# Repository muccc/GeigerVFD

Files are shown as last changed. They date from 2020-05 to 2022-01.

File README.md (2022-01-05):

# Geiger counter with Vacuum fluorescent display
This repo is a collection of all the parts to build an [ESP32](https://www.espressif.com/en/products/socs/esp32) based handheld device to measure radioactivity with a [Geiger–Müller tube](https://en.wikipedia.org/wiki/Geiger%E2%80%93M%C3%BCller_tube) & display info on an [VFD](https://en.wikipedia.org/wiki/Vacuum_fluorescent_display).

Future plans are [Home Automation](https://esphome.io/) integration, logging radioactivity measurements over WiFi & displaying additional information like e.g. a Clock.

The device is be powered via Micro-USB port of the ESP32. Note that the current draw of the VFD may exceed the 500mA USB standard.

# PCB
The PCB is designed in [KiCad](https://www.kicad.org/). All source files are in the  [pcb](pcb) Subdirectory.

### Schematic:
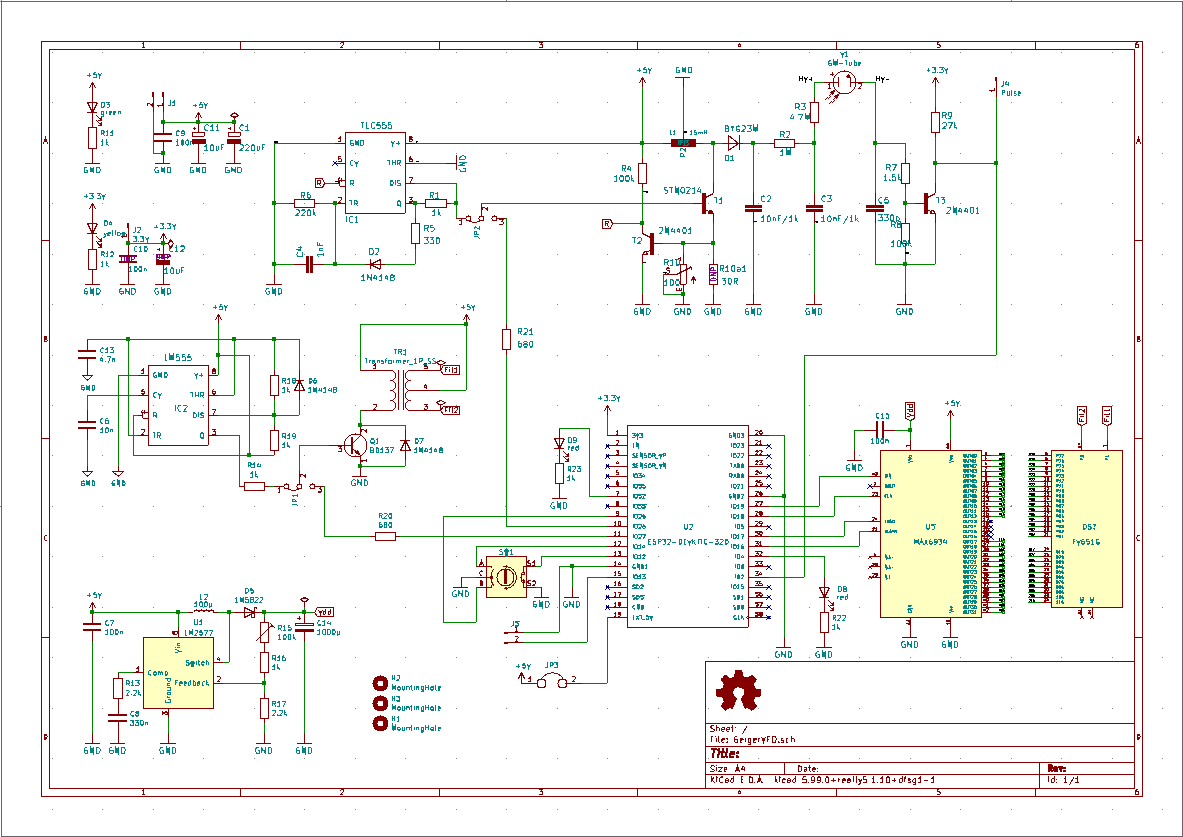
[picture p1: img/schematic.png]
schematic


### PCB:
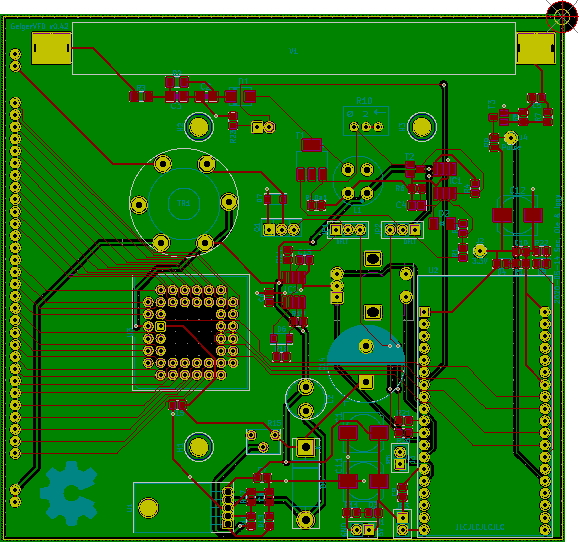
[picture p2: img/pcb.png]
pcb


### 3d render view:
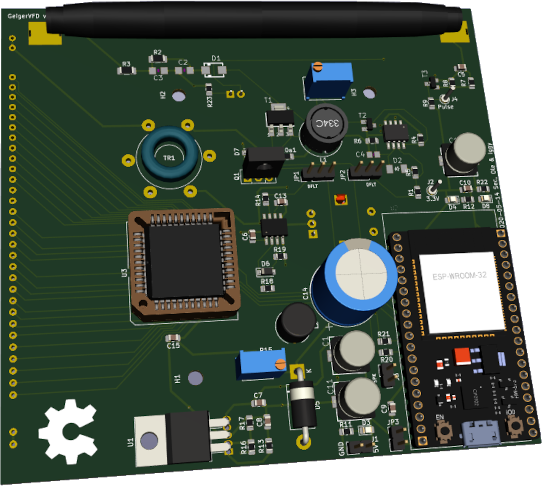
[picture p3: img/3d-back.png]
3d render back
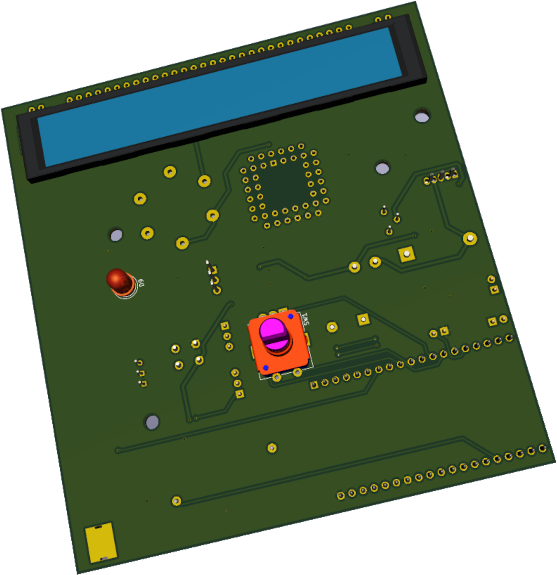
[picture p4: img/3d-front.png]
3d render front
 

# Case
The Case is designed in [OpenSCAD](https://openscad.org/). Sources reside in the [case](case/) Subdirectory.

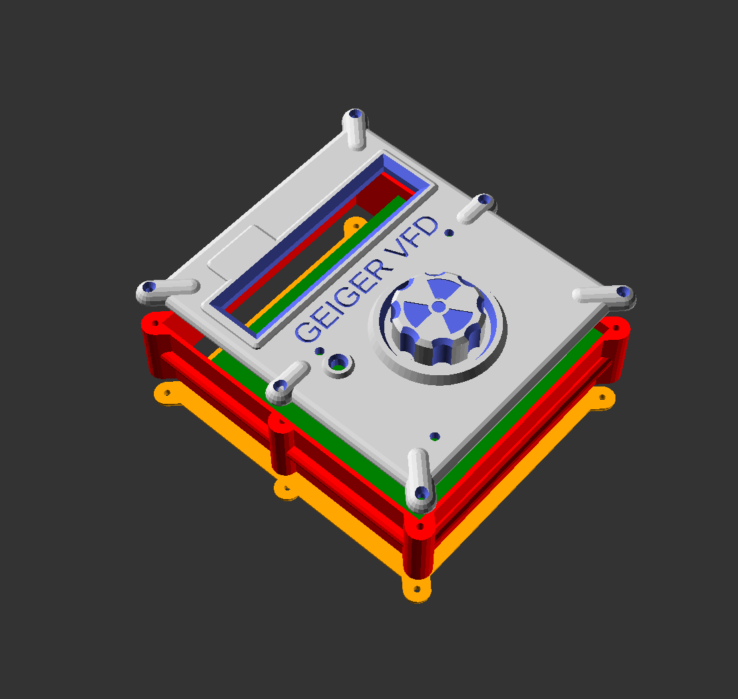
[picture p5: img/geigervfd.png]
plot


# Firmware
:warning: Work in Progress :warning:

The firmware is written using [Espressif-IDF](https://docs.espressif.com/projects/esp-idf/en/latest/esp32/get-started/) and lives in the [firmware](firmware/) directory.

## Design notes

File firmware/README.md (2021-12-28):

# Firmware for GeigerVFD

Standalone firmware for the GeigerVFD board

## Requirements

* Espressif IDF (https://docs.espressif.com/projects/esp-idf/en/latest/esp32/get-started/)

## Building

source ..../esp-idf/export.sh
idf.py build
idf.py flash

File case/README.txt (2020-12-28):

Geiger VFD case created by iggy@muc.ccc.de in OpenSCAD

inspired by https://twitter.com/80level/status/1240705664961449986

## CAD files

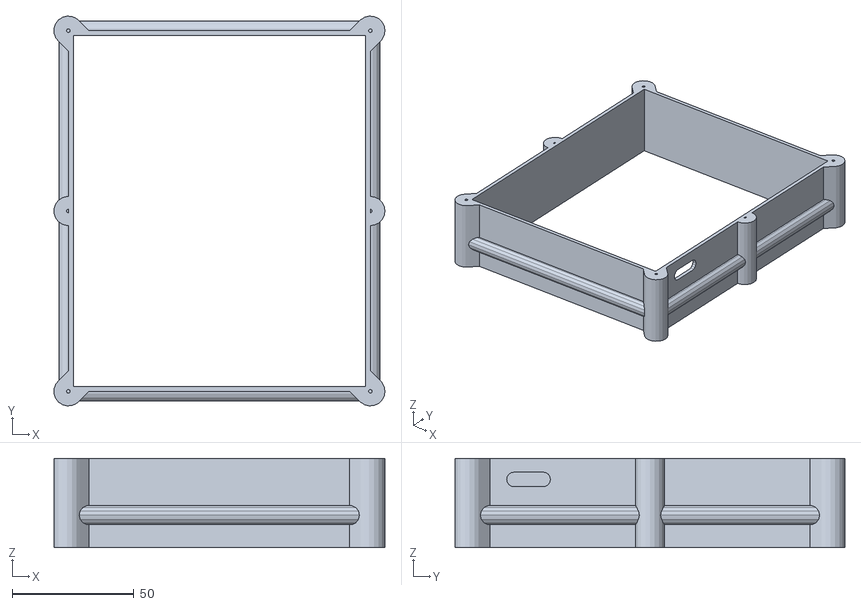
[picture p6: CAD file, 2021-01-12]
case/geigervfd_body.stl
136.1 x 160.3 x 36.6

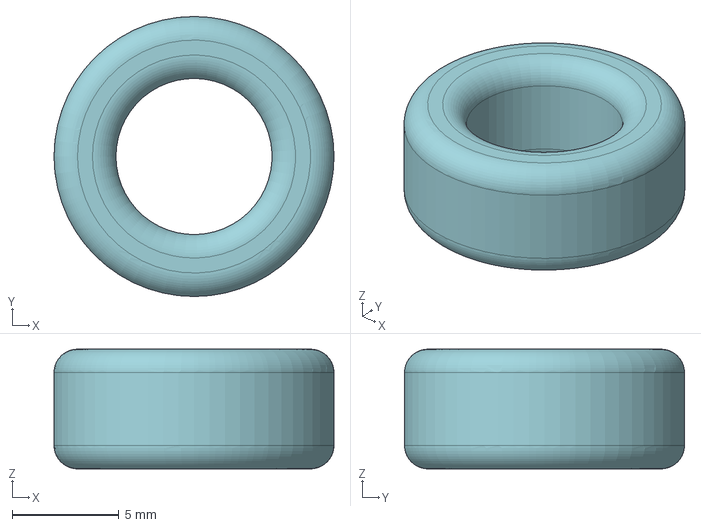
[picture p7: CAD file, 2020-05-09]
pcb/3d/Ferrite Core - EPCOS B64290L0044X038.step
13.1 x 13.1 x 5.60 mm

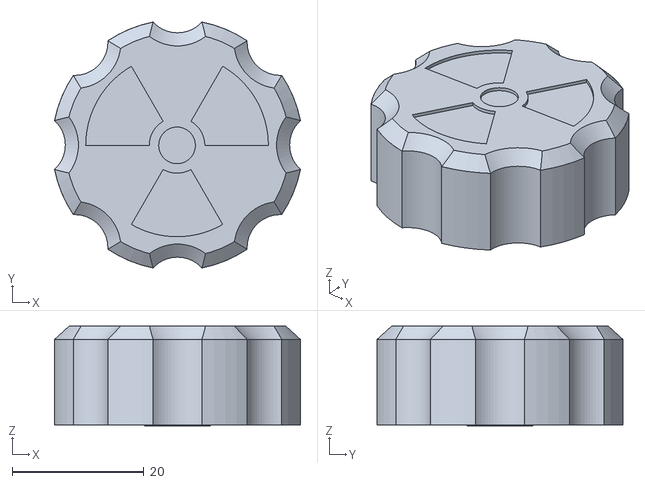
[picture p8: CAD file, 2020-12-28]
case/geigervfd_knob.stl
37.3 x 37.3 x 15.1

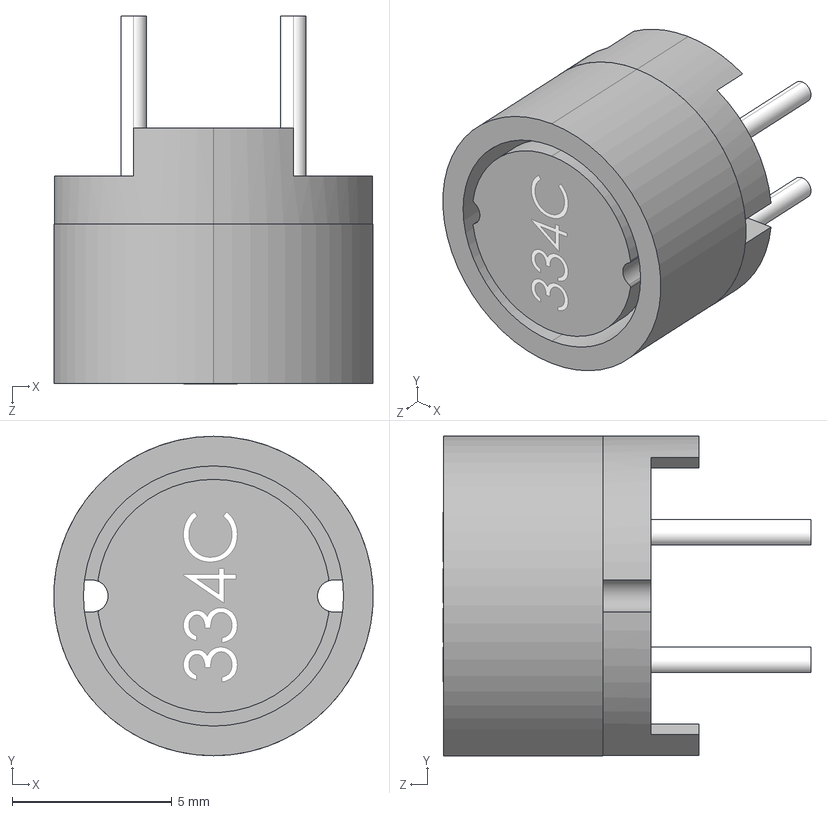
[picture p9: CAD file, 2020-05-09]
pcb/3d/mps_mag_1200lrs_thd_a.STEP
9.98 x 10.00 x 11.5 mm

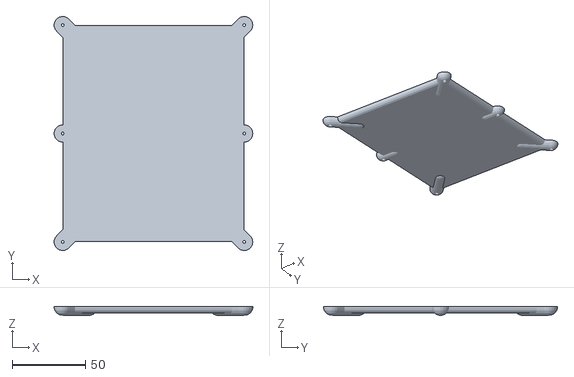
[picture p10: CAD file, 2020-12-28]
case/geigervfd_cover_bottom.stl
136.0 x 160.2 x 5.93

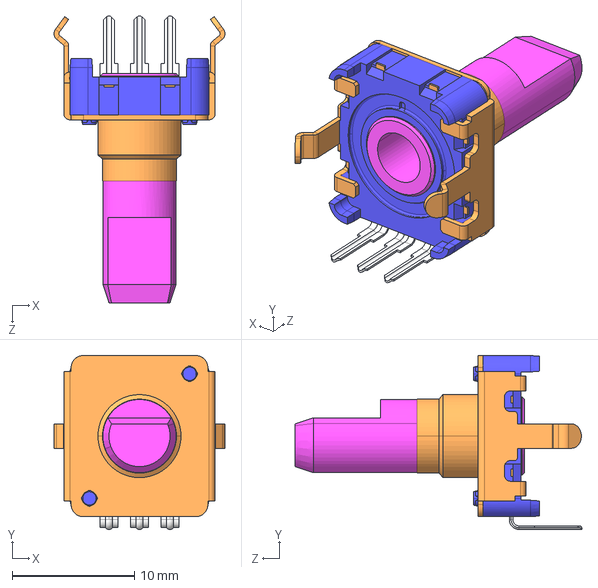
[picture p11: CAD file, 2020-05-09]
pcb/3d/EC12E-200.STEP
14.0 x 14.2 x 23.5 mm

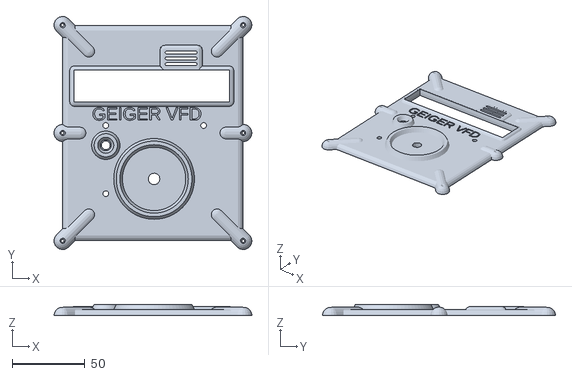
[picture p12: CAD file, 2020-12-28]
case/geigervfd_cover_top.stl
136.0 x 160.2 x 7.90

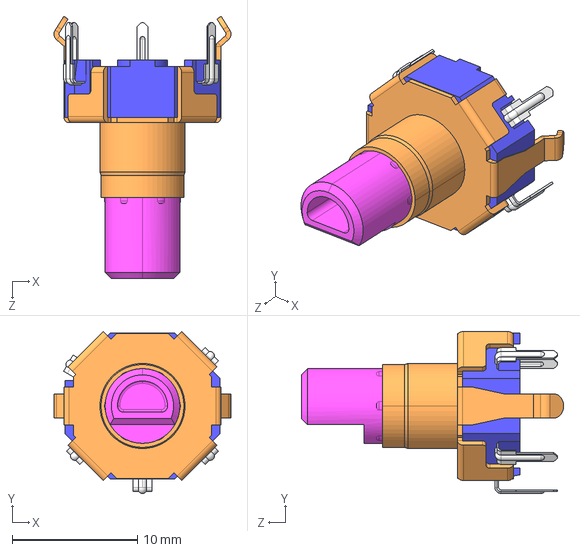
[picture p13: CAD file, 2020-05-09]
pcb/3d/EC12D1524403.step
14.1 x 13.0 x 21.0 mm

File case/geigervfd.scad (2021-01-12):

use<knob.scad>;

eps=0.01;

pcb_x = 109.7;
pcb_y = 117.35;
pcb_z = 1.6;

pcb_pad_top = 3;
pcb_pad_bottom = 27+5;
pcb_fit=1;

pcb_mount_holes = [ [23.2,29.46],
                    [23.2,76.32], 
                    [90.42,76.32] ];

pcb_led_pos = [23.2,62.74];//78.99];

pcb_mount_through = true;

pcb_mount_hole_d = 4;

case_wall_side = 2;

case_body_z = pcb_z+pcb_pad_top+pcb_pad_bottom;
//case_cover_h=5;

case_xl_oversize=3.5;
case_xr_oversize=5;

case_r=4.5;
case_y_oversize = 25;
case_cutout_dim=[pcb_x+2*pcb_fit+case_xl_oversize+case_xr_oversize,pcb_y+2*pcb_fit+case_y_oversize,case_body_z+2*eps];
case_body_dim=[case_cutout_dim[0]+2*case_wall_side,case_cutout_dim[1
]+2*case_wall_side,case_body_z];

case_offset = case_wall_side+pcb_fit;

case_top_dim=[case_body_dim[0],case_body_dim[1],case_r];
case_mount_d = 12;
case_mount_bore=1.5;
cover_mount_bore=2;

case_mounts=[[0,0,+1.5,+1.5],
            [0,case_body_dim[1],1.5,-1.5],
            [case_body_dim[0],0,-1.5,1.5],
            [case_body_dim[0],case_body_dim[1],-1.5,-1.5],
            [case_body_dim[0],case_body_dim[1]/2,-1,0],
            [0,case_body_dim[1]/2,1,0]
            ];

explode = 0;

usb_dim=[12,6];
usb_pos = [1,28.42/2+2.03+5];

has_buzzer=true;

display_size=[107,22,23];
display_pos=[1.3,92.38,-eps];

encoder_pos=[56.39,39.62,-eps];
encoder_bore=8;

module pcb(){
    translate([case_xl_oversize,0,0]) difference(){
        cube([pcb_x,pcb_y,pcb_z]);
        translate([0,0,-eps]) for (hole_pos=pcb_mount_holes)
            translate(hole_pos) cylinder(d=pcb_mount_hole_d, h=pcb_z+2*eps);
    }
}

module ring(d_ring, h_ring){
    difference(){
        cylinder(d1=d_ring+h_ring*3,d2=d_ring+h_ring*2,h=h_ring,$fn=64);
        cylinder(d1=d_ring,d2=d_ring+h_ring,h=h_ring+eps,$fn=64);
    }
}

module cube_rounded(dim,r,center=false){
    co = center?[0,0,-dim[2]/2]:[dim[0]/2,dim[1]/2];
    
    translate(co) hull() for(mx=[0,1], my=[0,1]) 
        mirror([mx,0,0])mirror([0,my,0])
        translate([(dim[0]/2)-r,(dim[1]/2)-r])
        cylinder(r=r, h=dim[2]);
}

module cube_cover(dim,center=false,invert=false) {
    co = center?[0,0,-dim[2]/2]:[dim[0]/2,dim[1]/2];
    r=dim[2];
    zz = invert?-dim[2]:0;
    translate(co) hull() for(mx=[0,1], my=[0,1]) 
        mirror([mx,0,0])mirror([0,my,0])
        translate([(dim[0]/2)-r,(dim[1]/2)-r])
        intersection(){
            sphere(r=r);
            translate([0,0,zz]) cylinder(r=dim[2],h=dim[2]);
        }
}

module body(){
    translate([0,0,-pcb_pad_bottom]) difference(){
        translate([-case_offset,-case_offset]){
        //union(){
            
            cube_rounded(case_body_dim,r=case_r);
            
            hull() for(ix=[0,1],iy=[0,1])translate([ix*case_body_dim[0],iy*case_body_dim[1],case_body_z/2-5]) sphere(r=case_r-0.5);
            
            for(mount = case_mounts)
                translate([mount[0],mount[1]]) mount_body(case_mount_d,case_body_z,mount[2],mount[3]);
        }
        translate([-pcb_fit,-pcb_fit,-eps]) cube(case_cutout_dim);
        
        
        //usb
        translate([pcb_x,usb_pos[1],pcb_pad_bottom-usb_dim[1]/2-usb_pos[0]])rotate([00,90,0]) hull() for(i=[-1,1]) translate([0,i*usb_dim[0]/2,0]) cylinder(d=usb_dim[1],h=60,center=true,$fn=16);
    }
}

module mount_body(d,h,dx=0,dy=0){
    difference(){
        hull(){
            cylinder(d=d,h=h);
            translate([dx*d,dy*d,0]) cylinder(d=d,h=h);
        }
        translate([0,0,-eps]) cylinder(d=case_mount_bore,h=h+2*eps,$fn=16);
    }
}

module mount_top(d,dx=0,dy=0,invert=false) {
    m=invert?1:0;
    mirror([0,0,m]) difference(){
        hull(){
            intersection(){
                sphere(d=d);
                cylinder(d=d,h=d);
            }
            translate([dx*d,dy*d,0]) intersection(){
                 sphere(d=d);
                 cylinder(d=d,h=d);
            }
        }
        translate([0,0,-eps]) cylinder(d=cover_mount_bore,h=d+2*eps,$fn=16);
        translate([0,0,d/2-case_mount_bore]) cylinder(d1=case_mount_bore,d2=cover_mount_bore*2,h=case_mount_bore,$fn=16);
    }
}
module cover(is_bottom=false){
    oz= is_bottom?-pcb_pad_bottom:pcb_pad_top+pcb_z;
    translate([-case_offset,-case_offset,oz]){
        difference(){
            cube_cover(case_top_dim,invert=is_bottom);
            
            for(i=[4,5]) translate([case_mounts[i][0],case_mounts[i][1],-10])cylinder(d=cover_mount_bore,h=20);
            
        }
            for(mount = case_mounts)
                translate([mount[0],mount[1]]) mount_top(case_mount_d,mount[2],mount[3],invert=is_bottom);
    }
}

module cover_bottom(){
    cover(is_bottom=true);
}

module cover_top() {
    z_top = case_r+pcb_pad_top;
    difference(){
        union(){
            cover(is_bottom=false);
            
            over =7.2;
            
            //display
            translate([case_xl_oversize,0,0])translate([-over/2,-over/2,z_top-0.5]) translate(display_pos) cube_cover([display_size[0]+over,display_size[1]+over,4]);
            
            //buzzer
            if(has_buzzer) translate([case_xl_oversize,0,0]) translate([60,112,z_top]) cube_cover([30,20,3.5]);
            
            //encoder
            translate([case_xl_oversize,0,0]) translate([0,0,z_top]) translate(encoder_pos) ring(42,5);
            
            //led
            translate([case_xl_oversize,0,0]) translate([0,0,z_top]) translate(pcb_led_pos) ring(6,5);
        }
        translate([case_xl_oversize,0,0]) translate(display_pos) cube(display_size);
            
        over2 = 1;
        //display
        translate([case_xl_oversize,0,0]) translate(display_pos) hull(){
            translate([0,0,z_top]) cube([display_size[0],display_size[1],eps]);
            translate([-over2/2,-over2/2,z_top+3])cube([display_size[0]+over2,display_size[1]+over2,eps]);
        }
        translate([case_xl_oversize,0,0]) translate(encoder_pos) cylinder(d=encoder_bore,h=23);
        translate([case_xl_oversize,0,0]) translate([0,0,-eps]) for (mount=pcb_mount_holes) translate(mount) cylinder(d=pcb_mount_hole_d,h=case_r+2*eps+10,$fn=16);
            
        translate([pcb_x/2,80,z_top]) linear_extrude(2)color("black") text("GEIGER VFD",halign="center", font="StalinistOne",size=9);
        
        translate([case_xl_oversize,0,0]) translate(pcb_led_pos) cylinder(d=6,h=case_r+2*eps+10,$fn=16);
    
        if(has_buzzer) translate([case_xl_oversize,0,0]) translate([60,111.5,z_top])
            for(i=[0:2]) {
                translate([0,i*4+7,0]) 
                hull() for(j=[0,1]) translate([j*20+5,0,0]) cylinder(d=2,h=10,$fn=16,center=true);
        }
    }
    if(false) translate([0,0,pcb_z]) for (mount=pcb_mount_holes) translate(mount) difference(){
        cylinder(d=pcb_mount_hole_d*2,h=pcb_pad_top,$fn=16);
        #translate([0,0,-eps]) cylinder(d=pcb_mount_hole_d,h=pcb_pad_top,$fn=16);
    }
}

//color("green") pcb();
color("red") body();

translate([0,0,explode])  cover_top();
translate([0,0,-explode]) color("orange") cover_bottom();
translate([case_xl_oversize,0,0]) translate([encoder_pos[0],encoder_pos[1], pcb_pad_top+case_r+1*explode]) knob();

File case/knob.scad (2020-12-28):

eps = 0.01;
$fn=64;

knob_d = 38;
knob_h = 15;
knob_chamfer=2;

grab_n = 8;
grab_d = 10;
grab_offset=3;

back_d=knob_d-10;
back_h=knob_h-4;

axis_h=0.1;
axis_d=6;
axis_d_flat=5;
axis_flat_offset=4;
axis_d_i=3.2;



module engraving(){
    translate([-0.4,0.5]) linear_extrude(2) scale([0.055,0.055]) import("rad.svg");
    //for(dia=[13,26]) difference(){
    //    cylinder(d=dia,h=2);
    //    translate([0,0,eps]) cylinder(d=dia-1,h=2);
    //}
}

module cylinder_chamfered(d,h,c,c_out=false){
    cdir= c_out?-1:1;
    cylinder(d=d,h=h+eps-c);
    translate([0,0,h-c]) cylinder(d1=d,d2=d-(cdir*c*2),h=c);
}

module knob(){
    difference(){
        union(){
            //main
            cylinder_chamfered(h=knob_h, d=knob_d, c=knob_chamfer);
        }
        
        //grab cutouts
        for(az=[0:360/grab_n:360]) rotate([0,0,az]) translate([knob_d/2+grab_offset,0,-eps]) cylinder_chamfered(d=grab_d,h=knob_h+2*eps,c=knob_chamfer, c_out=true);
    
        //back cutout
        translate([0,0,-eps]) cylinder(d=back_d,h=back_h);
        
        translate([0,0,knob_h-0.5]) engraving();
    }
    
    //axis
    
    
    difference(){
        union(){
            for(az=[0,90]) rotate([0,0,az]) translate([0,0,back_h/2]) cube([back_d+eps,1,back_h],center=true);

            translate([0,0,-axis_h+eps]) cylinder(d=axis_d+4,h=axis_h-eps);
            cylinder(d2=axis_d*2+4,d1=axis_d+4,h=back_h);

        }
        
        difference(){
            translate([0,0,-axis_h]) cylinder(d=axis_d,h=axis_h+knob_h);
                
            translate([axis_d_flat,0,-(axis_h)/2+(knob_h/2)]) cube([axis_d,axis_d,axis_h+knob_h+eps],center=true);
            
        }
    }
}

rotate([180,0,0]) knob();

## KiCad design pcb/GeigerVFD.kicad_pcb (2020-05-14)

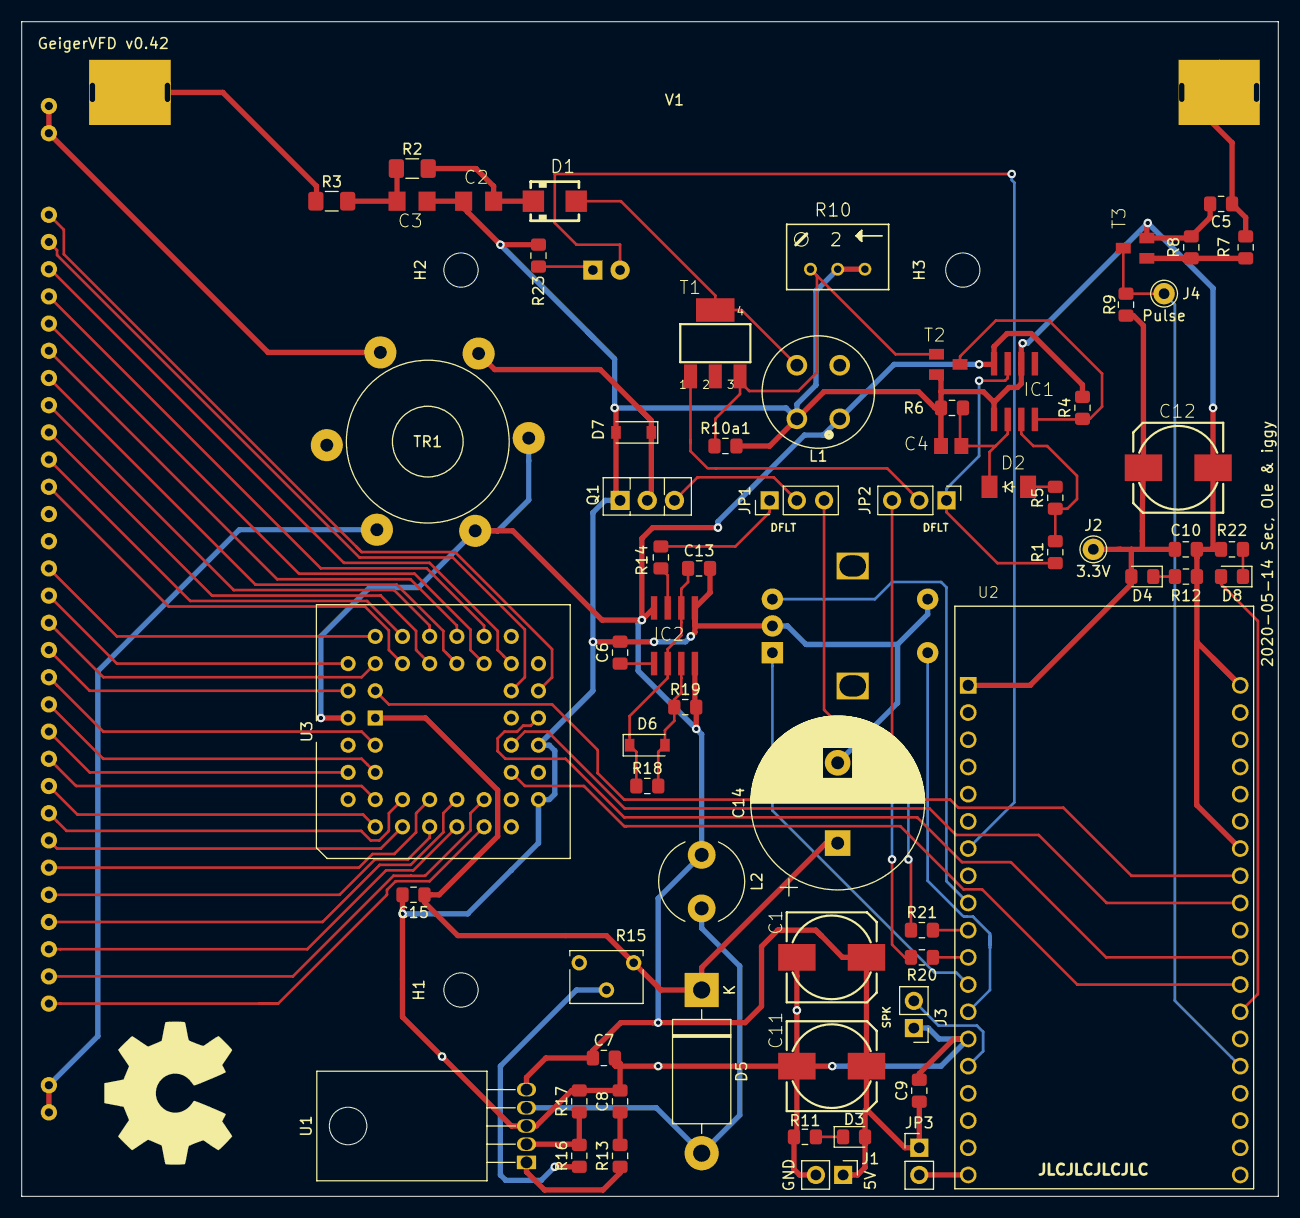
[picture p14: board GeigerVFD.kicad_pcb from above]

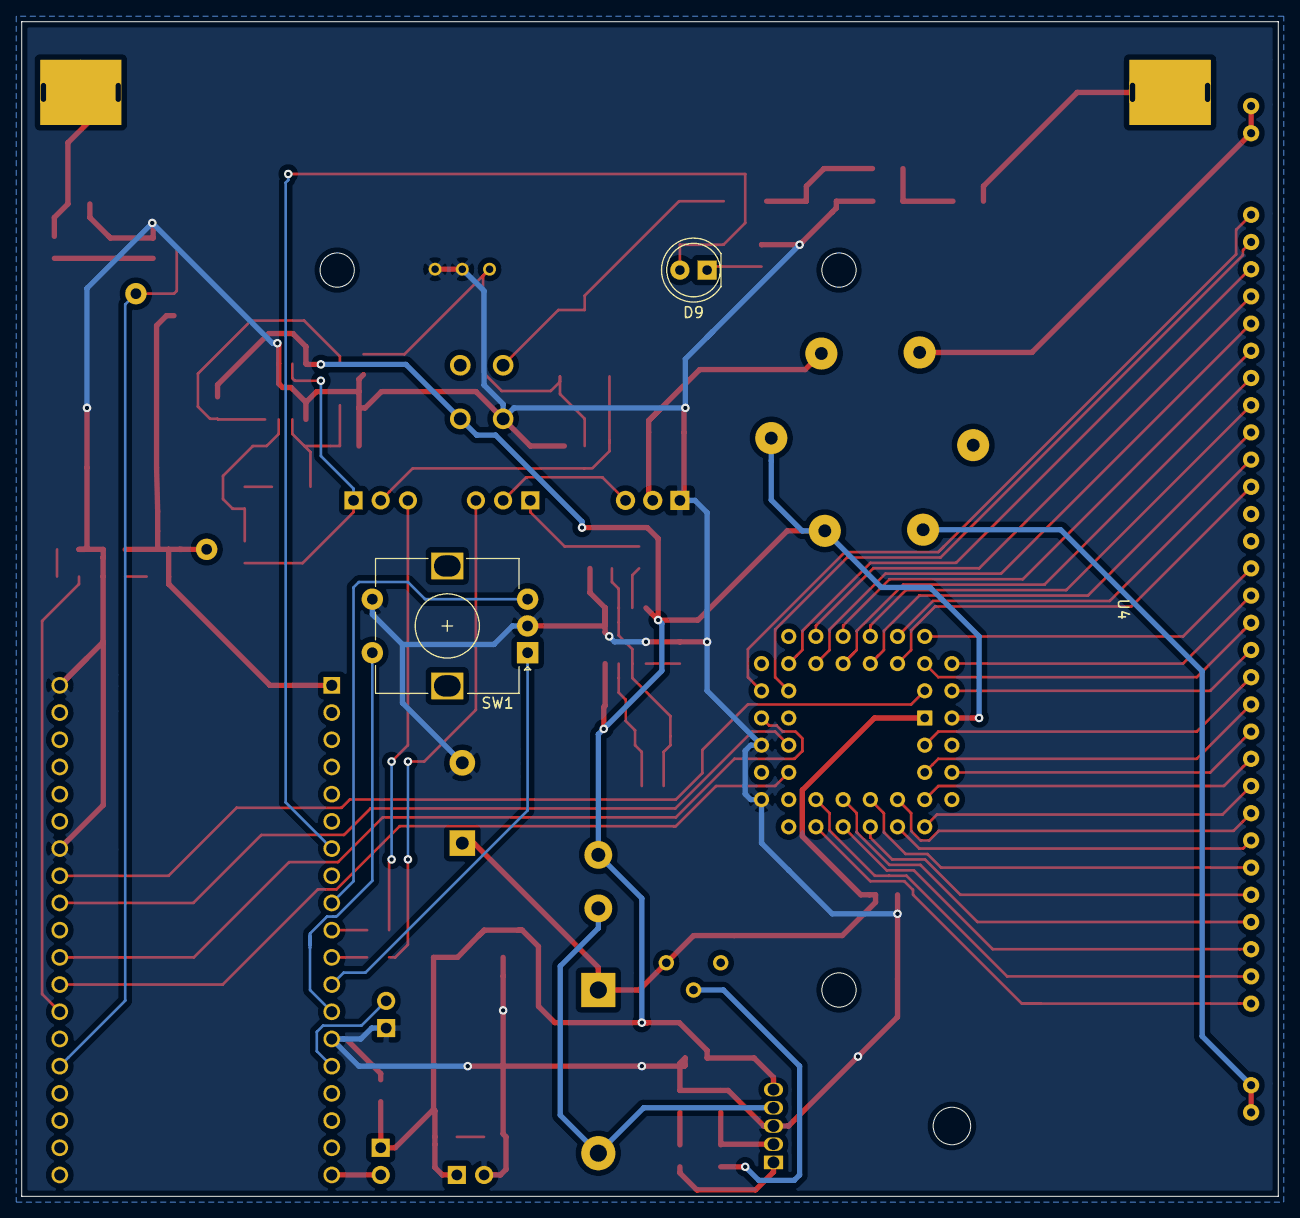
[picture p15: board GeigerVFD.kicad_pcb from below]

Board: 2 copper layers, 117.3 x 109.7 mm, 74 parts (3 on the bottom side), 79 nets.

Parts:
C1: 220uF; 153CLV-0810
C2, C3: 10nF/1k; C1206
C4: 1nF; C0805
C5: 330p; C_0805_2012Metric_Pad1.15x1.40mm_HandSolder
C6: 10n; C_0805_2012Metric_Pad1.15x1.40mm_HandSolder
C7, C9, C10, C15: 100n; C_0805_2012Metric_Pad1.15x1.40mm_HandSolder
C8: 330n; C_0805_2012Metric_Pad1.15x1.40mm_HandSolder
C11, C12: 10uF; 153CLV-0810
C13: 4.7n; C_0805_2012Metric_Pad1.15x1.40mm_HandSolder
C14: 1000µ; CP_Radial_D16.0mm_P7.50mm
D1: BYG23M; SMA
D2: 1N4148; SOD-123_MINI-SMA
D3: green; LED_0805_2012Metric_Pad1.15x1.40mm_HandSolder
D4: yellow; LED_0805_2012Metric_Pad1.15x1.40mm_HandSolder
D5: 1N5822; D_DO-201AD_P15.24mm_Horizontal
D6, D7: 1N4148; D_SOD-123
D8: red; LED_0805_2012Metric_Pad1.15x1.40mm_HandSolder
D9: red; LED_D5.0mm
H1, H2, H3: MountingHole; MountingHole_3.2mm_M3_DIN965
IC1: TLC555; SO08
IC2: LM555; SO08
J1, J3: Conn_01x02_Male; PinHeader_1x02_P2.54mm_Vertical
J2: 3.3V; Pin_D1.0mm_L10.0mm
J4: Pulse; Pin_D1.0mm_L10.0mm
JP1, JP2: Jumper3; PinHeader_1x03_P2.54mm_Vertical
JP3: Jumper; PinHeader_1x02_P2.54mm_Vertical
L1: 15mH; 1200LRS
L2: 100µ; L_Radial_D7.8mm_P5.00mm_Fastron_07HCP
LOGO1: Logo_Open_Hardware_Large; OSHW-Symbol_13.4x12mm_SilkScreen
Q1: BD137; TO-126-3_Vertical
R1, R11, R12, R14, R16, R18, R19, R22, R23: 1k; R_0805_2012Metric_Pad1.15x1.40mm_HandSolder
R2: 1M; R_1206_3216Metric_Pad1.42x1.75mm_HandSolder
R3: 4.7M; R_1206_3216Metric_Pad1.42x1.75mm_HandSolder
R4, R8: 100k; R_0805_2012Metric_Pad1.15x1.40mm_HandSolder
R5: 330; R_0805_2012Metric_Pad1.15x1.40mm_HandSolder
R6: 220k; R_0805_2012Metric_Pad1.15x1.40mm_HandSolder
R7: 1.5k; R_0805_2012Metric_Pad1.15x1.40mm_HandSolder
R9: 27k; R_0805_2012Metric_Pad1.15x1.40mm_HandSolder
R10: 100; RJ9W
R10a1: 30R; R_0805_2012Metric_Pad1.15x1.40mm_HandSolder
R13, R17: 2.2k; R_0805_2012Metric_Pad1.15x1.40mm_HandSolder
R15: 100k; Potentiometer_Vishay_T73XX_Horizontal
R20, R21: 680; R_0805_2012Metric_Pad1.15x1.40mm_HandSolder
SW1: Rotary_Encoder_Switch; RotaryEncoder_Alps_EC12E-Switch_Vertical_H20mm
T1: STN0214; SOT223
T2, T3: 2N4401; SOT23
TR1: Transformer_1P_SS; Transformer_Toroid_Tapped_Horizontal_D14.0mm_Amidon-T50
U1: LM2577; TO-220-5_Horizontal_TabDown
U2: ESP32-DEVKITC-32D; MODULE_ESP32-DEVKITC-32D
U3: MAX6934; PLCC-44_THT-Socket
U4: FV651G
V1: GM-Tube; Tube

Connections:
+3V3: C10.1, C12.+, D4.2, J2.1, R9.2, U2.1
+5V: C1.+, C7.1, C9.1, C11.+, D3.2, IC1.8, IC2.4, IC2.8, J1.1, JP3.1, L1.P1, L2.1, R4.2, R19.2, TR1.1, TR1.4, U1.5, U3.44
/01G: U3.38, U4.24
/02G: U3.37, U4.25
/03G: U3.36, U4.26
/04G: U3.35, U4.27
/05G: U3.34, U4.28
/06G: U3.33, U4.29
/07G: U3.32, U4.30
/08G: U3.31, U4.31
/09G: U3.30, U4.32
/10G: U3.27, U4.33
/11G: U3.26, U4.34
/HV+: R3.1, V1.1
/HV-: C5.1, R7.1, V1.2
/P01: U3.39, U4.21
/P02: U3.40, U4.20
/P03: U3.41, U4.19
/P04: U3.42, U4.18
/P05: U3.3, U4.17
/P06: U3.5, U4.16
/P07: U3.4, U4.15
/P08: U3.8, U4.14
/P09: U3.7, U4.13
/P10: U3.10, U4.12
/P11: U3.9, U4.11
/P12: U3.12, U4.10
/P13: U3.11, U4.9
/P14: U3.14, U4.8
/P15: U3.13, U4.7
/P16: U3.16, U4.6
/P17: U3.15, U4.5
Fil1: TR1.5, U4.1, U4.2
Fil2: TR1.3, U4.37, U4.38
GND: C1.-, C2.2, C3.2, C4.1, C5.2, C6.2, C7.2, C8.2, C9.2, C10.2, C11.-, C12.-, C13.2, C14.2, C15.2, D7.2, IC1.1, IC1.6, IC2.1, J1.2, J3.1, L1.P4, Q1.1, R6.2, R8.2, R10.E, R10.S, R10a1.2, R11.2, R12.2, R17.2, R22.2, R23.2, SW1.C, SW1.S2, T2.2, T3.2, U1.3, U2.14, U2.20, U2.26, U3.18, U3.22
unnamed: C2.1, D1.C, R2.2
unnamed: C3.1, R2.1, R3.2
unnamed: C4.2, D2.C, IC1.2, R6.1
unnamed: C6.1, IC2.5
unnamed: C8.1, R13.2
unnamed: C13.1, D6.1, IC2.2, IC2.6, R18.1
unnamed: D1.A, L1.P3, T1.4
unnamed: D2.A, R5.2
unnamed: D3.1, R11.1
unnamed: D4.1, R12.1
unnamed: D5.2, L2.2, U1.4
unnamed: D6.2, IC2.7, R18.2, R19.1
unnamed: D7.1, Q1.2, TR1.2
unnamed: D8.1, R22.1
unnamed: D8.2, U2.32
unnamed: D9.1, R23.1
unnamed: D9.2, U2.7
unnamed: IC1.3, R1.2, R5.1
unnamed: IC1.7, JP2.1, R1.1
unnamed: IC2.3, R14.2
unnamed: J3.2, U2.15
unnamed: J4.1, R9.1, T3.3, U2.34
unnamed: JP1.1, R14.1
unnamed: JP1.2, Q1.3
unnamed: JP1.3, R20.2
unnamed: JP2.2, T1.1
unnamed: JP2.3, R21.1
unnamed: JP3.2, U2.19
unnamed: R7.2, R8.1, T3.1
unnamed: R10.A, R10a1.1, T1.3, T2.1
unnamed: R13.1, U1.1
unnamed: R15.2, R16.1
unnamed: R16.2, R17.1, U1.2
unnamed: R20.1, U2.11
unnamed: R21.2, U2.10
unnamed: SW1.A, U2.12
unnamed: SW1.B, U2.9
unnamed: SW1.S1, U2.13
unnamed: U2.27, U3.43
unnamed: U2.28, U3.23
unnamed: U2.30, U3.24
unnamed: U2.31, U3.21
R: IC1.4, R4.1, T2.3
Vdd: C14.1, C15.1, D5.1, R15.1, U3.1

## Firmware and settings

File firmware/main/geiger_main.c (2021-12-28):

/* Hello World Example

   This example code is in the Public Domain (or CC0 licensed, at your option.)

   Unless required by applicable law or agreed to in writing, this
   software is distributed on an "AS IS" BASIS, WITHOUT WARRANTIES OR
   CONDITIONS OF ANY KIND, either express or implied.
*/
#include <stdio.h>
#include <stdlib.h>
#include <string.h>
#include <unistd.h>
#include "sdkconfig.h"
#include "freertos/FreeRTOS.h"
#include "freertos/task.h"
#include "freertos/queue.h"
#include "driver/gpio.h"
#include "driver/spi_master.h"
#include "driver/ledc.h"
#include "esp_system.h"
#include "esp_spi_flash.h"
#include "esp_timer.h"
#include "esp_log.h"

#include "rotary_encoder.h"

/* esp32 GPIO pin mappings */
#define PIN_LED    32
#define PIN_PWRLED  4

#define PIN_LOAD   17
#define PIN_BLANK  16
#define PIN_CLK    18
#define PIN_DIN    19

#define PIN_BRIGHT 27

#define PIN_ROT1   14
#define PIN_ROT2   25

/* OUT pins of MAX6934 */
#define OUT(x) (1<<(31-x))

/* VFD - G pins */
#define G01 OUT(27)  // symbols
#define G02 OUT(26)  // rightmost
#define G03 OUT(25)
#define G04 OUT(24)
#define G05 OUT(23)
#define G06 OUT(22)
#define G07 OUT(21)
#define G08 OUT(20)
#define G09 OUT(19)
#define G10 OUT(18)
#define G11 OUT(17)  // leftmost

unsigned int grids[]={G11,G10,G09,G08,G07,G06,G05,G04,G03,G02,G01};  // left to right

/* VFD - P pins */
#define P01 OUT(28)  /* s1 */
#define P02 OUT(29)  /* s2 */
#define P03 OUT(30)  /* a  */
#define P04 OUT(31)  /* b  */
#define P05 OUT( 0)  /* f  */
#define P06 OUT( 2)  /* k  */
#define P07 OUT( 1)  /* j  */
#define P08 OUT( 4)  /* h  */
#define P09 OUT( 3)  /* m  */
#define P10 OUT( 6)  /* g  */
#define P11 OUT( 5)  /* n  */
#define P12 OUT( 8)  /* p  */
#define P13 OUT( 7)  /* r  */
#define P14 OUT(10)  /* c  */
#define P15 OUT( 9)  /* e  */
#define P16 OUT(12)  /* d  */
#define P17 OUT(11)  /* s3 */

/* P locations according to VFD datasheet:
    ---    a           3
   |\|/| fhjkb   5  8  7  6  4
    - -   g m      10     9
   |/|\| erpnc  15 13 12 11 14
    ---    d          16
 */

const int ascii[] = {
	P03|P05|P04|P10|P09|P15|P14,  /* a */
//	P05|P08|P10|P15|P13,          /* b */
//	P05|P15|P03|P16|P06|P11|P10,  /* b v2 */
	P05|P15|P10|P09|P14|P16,      /* b small */
	P03|P05|P15|P16,              /* c */
//	P05|P08|P15|P13,              /* d */
	P15|P10|P09|P16|P04|P14,      /* d small */
	P03|P05|P10|P15|P16,          /* e */
	P03|P05|P10|P15,              /* f */
	P03|P05|P15|P16|P11,          /* g */
	P05|P15|P10|P09|P04|P14,      /* h */
	P07|P12,                      /* i */
//	P07|P12|P16|P15,              /* j */
	P04|P14|P16|P15,              /* j v2 */
//	P07|P06|P12|P11,              /* k */
	P05|P15|P10|P06|P11,          /* k new */
	P05|P15|P16,                  /* l */
	P05|P15|P03|P07|P04|P14,      /* m */
	P05|P15|P03|P04|P14,          /* n */
	P03|P05|P04|P15|P14|P16,      /* o */
	P03|P05|P04|P15|P10|P09,      /* p */
	P03|P05|P04|P15|P14|P16|P11,  /* q */
	P03|P05|P15|P04|P09|P10|P11,  /* r */
//	P03|P07|P04|P09|P11|P12,      /* r v2 */
	P03|P05|P10|P09|P14|P16,      /* s */
	P03|P07|P12,                  /* t */
	P05|P15|P16|P04|P14,          /* u */
	P05|P15|P13|P06,              /* v */
	P05|P15|P16|P04|P14|P12,      /* w */
	P08|P06|P13|P11,              /* x */
	P08|P06|P12,                  /* y */
//	P03|P06|P13|P16,              /* z */
	P03|P06|P13|P16|P10|P09,      /* z v2 */
};


const int digit[] = {
	P03|P05|P04|P14|P15|P16,         // 0
	P04|P14,                         // 1
	P03|P04|P10|P09|P15|P16,         // 2
	P03|P04|P10|P09|P14|P16,         // 3
	P05|P10|P09|P04|P14,             // 4
	P03|P05|P10|P09|P14|P16,         // 5
	P03|P05|P10|P09|P15|P14|P16,     // 6
	P03|P04|P14,                     // 7
	P03|P05|P04|P10|P09|P15|P14|P16, // 8
	P03|P05|P04|P10|P09|P14|P16,     // 9
};


/* special symbols
             s1 s2 s3
	11G  <  >
	10G  bd
	09G  B  C
	08G
	07G  [] [] :
	06G  [] []
	05G  [] []
	04G  [] []
	03G  [] []
	02G  <  <
	01G  CCC -> <- ( ) analog digital (p11 - p17)
 */

#define SYM_CCC        G01|P11
#define SYM_LEFTARROW  G01|P12
#define SYM_RIGHTARROW G01|P13
#define SYM_LEFTPAREN  G01|P14
#define SYM_RIGHTPAREN G01|P15
#define SYM_ANALOG     G01|P16
#define SYM_DIGITAL    G01|P17
#define SYM_COLON      G07|P17
#define SYM_LEFT       G11|P01
#define SYM_RIGHT      G11|P02
#define SYM_DOLBY      G10|P01
#define SYM_B          G09|P01
#define SYM_C          G09|P02
#define SYM_PIP0       G07|P02
#define SYM_PIP1       G07|P01
#define SYM_PIP2       G06|P02
#define SYM_PIP3       G06|P01
#define SYM_PIP4       G05|P02
#define SYM_PIP5       G05|P01
#define SYM_PIP6       G04|P02
#define SYM_PIP7       G04|P01
#define SYM_PIP8       G03|P02
#define SYM_PIP9       G03|P01
#define SYM_REV_L      G02|P01
#define SYM_REV_R      G02|P02

unsigned int const pips[]={ SYM_PIP0, SYM_PIP1, SYM_PIP2, SYM_PIP3, SYM_PIP4, SYM_PIP5, SYM_PIP6, SYM_PIP7, SYM_PIP8, SYM_PIP9};

/* display high level */
#define DISPLAY_LEN 11
#define DISPLAY_TEXT_LEN (DISPLAY_LEN-1)
unsigned int outbuf[DISPLAY_LEN] = {0,0,0,0,0,0,0,0,0,0,0};

void vfd_write(char *str, unsigned char flags){
	int out=0;
	int in=0;

	// clear display
	for (out=0;out<DISPLAY_LEN;out++)
		outbuf[out]=0;

	out=DISPLAY_TEXT_LEN-strlen(str); // right-justify by default
	assert(out>=0);
	if (out<0)
		out=0;

	while ( str[in]!=0 && (in+out)<DISPLAY_TEXT_LEN ){
		char c=str[in];
		if (c>='0' && c<='9')
			outbuf[in+out]=digit[c-'0'];
		else if (c>='a' && c<='z')
			outbuf[in+out]=ascii[c-'a'];
		else if (c=='_')
			outbuf[in+out]=P16;
		else if (c=='-')
			outbuf[in+out]=P10|P09;
		else if (c=='+')
			outbuf[in+out]=P10|P09|P07|P12;
		else if (c=='<')
			outbuf[in+out]=P06|P11;
		else if (c=='>')
			outbuf[in+out]=P08|P13;
		else if (c==' ')
			outbuf[in+out]=0;
		else
			outbuf[in+out]=P10; /* error indicator */
		in++;
	};
};

void vfd_symbol(int sym){
	int x;
	
	for(x=0;x<DISPLAY_LEN;x++){
		if (sym&grids[x])
			outbuf[x]|= sym & ~grids[x];
	};
};

/* display low level */
static void display_timer_callback(void* arg);

spi_device_handle_t spi; // global spi handle
spi_transaction_t spi_t;

void spi_post_transfer_callback(spi_transaction_t *t) {
	int dc=(int)t->user;
	if (dc==1){
		ets_delay_us(1);
		gpio_set_level(PIN_LOAD, 1);
		ets_delay_us(1);
		gpio_set_level(PIN_LOAD, 0);
	};
}

void setup_display_spi(){
	esp_err_t ret;
	spi_bus_config_t buscfg={
		.miso_io_num=-1,
		.mosi_io_num=PIN_DIN,
		.sclk_io_num=PIN_CLK,
		.quadwp_io_num=-1,
		.quadhd_io_num=-1,
		.max_transfer_sz=32,
	};
	spi_device_interface_config_t devcfg={
		.clock_speed_hz=1*1000*1000,         // Clock out at 1 MHz (max=5MHz?)
		.mode=0,                             // SPI mode 0
		.spics_io_num=-1,                    // no CS pin
		.queue_size=7,                       // We want to be able to queue 7 transactions at a time
		.post_cb=spi_post_transfer_callback, // callback to enable LOAD
	};

	//Initialize non-SPI GPIOs
	gpio_set_direction(PIN_LOAD,  GPIO_MODE_OUTPUT);
	gpio_set_direction(PIN_BLANK, GPIO_MODE_OUTPUT);
	gpio_set_level(PIN_LOAD,  0);
	gpio_set_level(PIN_BLANK, 0);

	//Initialize the SPI bus
	ret=spi_bus_initialize(SPI2_HOST, &buscfg, SPI_DMA_DISABLED);
	ESP_ERROR_CHECK(ret);
	//Attach the LCD to the SPI bus
	ret=spi_bus_add_device(SPI2_HOST, &devcfg, &spi);
	ESP_ERROR_CHECK(ret);

	/* prepare spi transaction */
	memset(&spi_t, 0, sizeof(spi_t));
	spi_t.length=32;
	spi_t.flags = SPI_TRANS_USE_TXDATA;
	spi_t.user = (void*)1;
}

void setup_display_timer(){
	const esp_timer_create_args_t periodic_timer_args = {
		.callback = &display_timer_callback,
		/* name is optional, but may help identify the timer when debugging */
		.name = "vfd_refresh"
	};

	esp_timer_handle_t periodic_timer;
	ESP_ERROR_CHECK(esp_timer_create(&periodic_timer_args, &periodic_timer));
	ESP_ERROR_CHECK(esp_timer_start_periodic(periodic_timer, 1000));

	printf("Started timers, time since boot: %lld us\n", esp_timer_get_time());

	/* Print debugging information about timers to console every 2 seconds */
//	for (int i = 0; i < 5; ++i) {
//		ESP_ERROR_CHECK(esp_timer_dump(stdout));
//		usleep(2000000);
//	}

	/* Remove timer */
//	ESP_ERROR_CHECK(esp_timer_stop(periodic_timer));
//	ESP_ERROR_CHECK(esp_timer_delete(periodic_timer));
}

void setup_display_pwm(){
	gpio_set_direction(PIN_BRIGHT, GPIO_MODE_OUTPUT);

	// should we use LEDC_HIGH_SPEED_MODE ?

	ledc_timer_config_t ledc_timer = {
		.duty_resolution = LEDC_TIMER_8_BIT, // resolution of PWM duty
		.freq_hz = 60000,                    // frequency of PWM signal
		.speed_mode = LEDC_LOW_SPEED_MODE,   // timer mode
		.timer_num = LEDC_TIMER_0,           // timer index
		.clk_cfg = LEDC_AUTO_CLK,            // Auto select the source clock
	};
	ledc_timer_config(&ledc_timer);

	ledc_channel_config_t ledc_channel = {
		.channel    = LEDC_CHANNEL_0,
		.duty       = 0,
		.gpio_num   = PIN_BRIGHT,
		.speed_mode = LEDC_LOW_SPEED_MODE,
		.hpoint     = 0,
		.timer_sel  = LEDC_TIMER_0
	};
	ledc_channel_config(&ledc_channel);

#define LEDC_TEST_DUTY         (1<<5)
	ledc_set_duty(ledc_channel.speed_mode, ledc_channel.channel, LEDC_TEST_DUTY);
	ledc_update_duty(ledc_channel.speed_mode, ledc_channel.channel);
}


static void display_timer_callback(void* arg){
	static unsigned int cur_g =0;
	esp_err_t ret;

	/* write next segment */
	cur_g=(cur_g+1)%DISPLAY_LEN;

//	printf("[timer] g: %2d (%8x), out: %8x\n",cur_g,grids[cur_g],outbuf[cur_g]);

	// ESP32 is little endian, so the bytes have to be swapped....
	unsigned int vfd=grids[cur_g] | outbuf[cur_g];
	spi_t.tx_data[0]=(vfd>>24)&0xff;
	spi_t.tx_data[1]=(vfd>>16)&0xff;
	spi_t.tx_data[2]=(vfd>>8) &0xff;
	spi_t.tx_data[3]=(vfd)    &0xff;

	// fire & forget
	ret = spi_device_queue_trans(spi, &spi_t, 0);
//    ret = spi_device_polling_transmit(spi, &spi_t);

	assert( ret == ESP_OK );
	ESP_ERROR_CHECK(ret);
}

/* rotary encoder */
rotary_encoder_t *encoder = NULL;

void setup_rotary(){
	// Rotary encoder underlying device is represented by a PCNT unit in this example
	uint32_t pcnt_unit = 0;

	// Create rotary encoder instance
	rotary_encoder_config_t config = ROTARY_ENCODER_DEFAULT_CONFIG((rotary_encoder_dev_t)pcnt_unit, PIN_ROT1, PIN_ROT2);
	ESP_ERROR_CHECK(rotary_encoder_new_ec11(&config, &encoder));

	// Filter out glitch (1us)
//    ESP_ERROR_CHECK(encoder->set_glitch_filter(encoder, 1));

	// Start encoder
	ESP_ERROR_CHECK(encoder->start(encoder));
}

/* utility functions */
void print_esp_info(){
	/* Print chip information */
	esp_chip_info_t chip_info;
	esp_chip_info(&chip_info);
	printf("This is %s chip with %d CPU core(s), WiFi%s%s, ",
			CONFIG_IDF_TARGET,
			chip_info.cores,
			(chip_info.features & CHIP_FEATURE_BT) ? "/BT" : "",
			(chip_info.features & CHIP_FEATURE_BLE) ? "/BLE" : "");

	printf("silicon revision %d, ", chip_info.revision);

	printf("%dMB %s flash\n", spi_flash_get_chip_size() / (1024 * 1024),
			(chip_info.features & CHIP_FEATURE_EMB_FLASH) ? "embedded" : "external");

	printf("Minimum free heap size: %d bytes\n", esp_get_minimum_free_heap_size());
}

/* */

void app_main(void)
{
	printf("Startup...\n");
	print_esp_info();
//	vTaskDelay(1000 / portTICK_PERIOD_MS);

	printf("GO!\n");
	setup_display_spi();
	setup_display_pwm();

	printf("Hello world!\n");
	vfd_write("<hello>",0);
	vfd_symbol(SYM_CCC);
	setup_display_timer();
	usleep(3000000);

	setup_rotary();

	gpio_set_direction(PIN_LED,    GPIO_MODE_OUTPUT);
	gpio_set_direction(PIN_PWRLED, GPIO_MODE_OUTPUT);

	char outstr[99];
	int i=0;
	int evo=0;
	while(1){
		i++;

		//printf("Running loop %d ...\n", i);
		vTaskDelay(20 / portTICK_PERIOD_MS);
		gpio_set_level(PIN_LED, i%2);
		gpio_set_level(PIN_PWRLED, i%2);

		/* Proper euklidean definitions */
#define MOD(a,b) ((a)%(b)+(((a)%(b)<0)?(b):0))
#define DIV(a,b) ((a)<0 ? ((a)-(b)+1)/(b) : (a)/(b))

		int ev=encoder->get_counter_value(encoder);
		int ev4=DIV((ev+1),4); // round up

		sprintf(outstr,"%d %c %3d",ev4,'a'+MOD(DIV(ev4,10),26),i);
		vfd_write(outstr,0);

		int evm=MOD(ev4,10);
		if (evm!=evo){
			printf("ev: %d, ev4: %d, evm: %d\n",ev,ev4,evm);
			evo=evm;
		};
		vfd_symbol(pips[evm]);
	};

	printf("Restarting now.\n");
	fflush(stdout);
	esp_restart();
}

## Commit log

2020-03-21 Created MAX6934 and VFD symbols
    [GeigerVFD.kicad_pcb, GeigerVFD.sch]
2020-03-21 Make pin text smaller
2020-03-25 Add Voltage generation
    [GeigerVFD.sch]
2020-04-06 connect vfd & add footprint
    [GeigerVFD.sch]
2020-04-29 Include Geiger circuit & replace ESP
    [GeigerVFD.kicad_pcb, GeigerVFD.sch]
2020-04-30 Update footprints
    [GeigerVFD.sch]
2020-05-05 Update footprints & fix bugs
    [GeigerVFD.kicad_pcb, GeigerVFD.sch]
2020-05-05 First sort of PCB
    [GeigerVFD.kicad_pcb, GeigerVFD.sch]
2020-05-07 Add GM-Tube. First pass at PCB
    [GeigerVFD.kicad_pcb, GeigerVFD.sch]
2020-05-07 Fix annotations of PiGi subsection. Fix some footprint issues. More PCB routing Add Geiger Tube
    [GeigerVFD.kicad_pcb, GeigerVFD.sch]
2020-05-07 Fix GM Tube Footprint Add Power flags for ERC Fix VFD symbol to use pin stacking
    [GeigerVFD.kicad_pcb, GeigerVFD.sch]
2020-05-09 Shrink & route & add rotary encoder & add 3d models
    [EC12D1524403.step, EC12E-200.STEP, Ferrite Core - EPCOS B64290L0044X038.step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]
2020-05-10 Convert Eagle R to Kicad Add Buzzer header & Warn LED
    [GeigerVFD.kicad_pcb, GeigerVFD.sch]
2020-05-13 Finish PCB
    [GeigerVFD.kicad_pcb]
2020-05-13 openscad files for case - initial commit
    [geigervfd.scad, knob.scad]
2020-12-28 change case dimensions according to reality
    [geigervfd.scad, knob.scad]
2020-12-28 Case: Replaced reference image with readme.txt
2020-12-28 fix in knob.scad
    [knob.scad]
2020-12-28 added .stl for all parts
    [geigervfd_body.stl, geigervfd_cover_bottom.stl, geigervfd_cover_top.stl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]
2021-01-12 increaded case bode height and moved usb cutout position
    [geigervfd.scad, geigervfd_body.stl]
2021-12-28 Move pcb things to own subdir
    [EC12D1524403.step, EC12E-200.STEP, Ferrite Core - EPCOS B64290L0044X038.step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]
